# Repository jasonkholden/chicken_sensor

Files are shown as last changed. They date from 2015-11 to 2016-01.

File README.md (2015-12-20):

#4-Input Temperature Sensor Daughter Board

This is a 4-input temperature sensor daughter board for the ESP8266

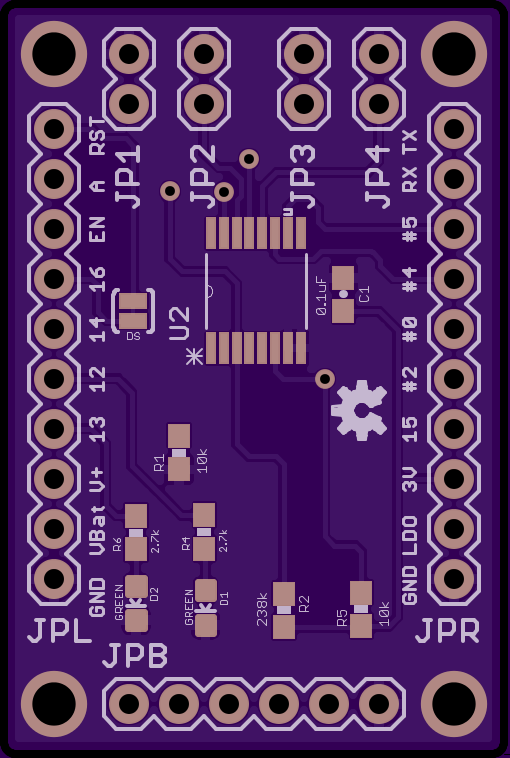
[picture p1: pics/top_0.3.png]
4-input temperature sensor Temperature Sensor


A detailed project writeup is available at [Making Electronics](http://makingelectronics.com/?q=node/3) on how to use this board to build a solar-powered IoT Temperature sensor

This daughter board will multiplex up to 4 10k thermistor inputs to the
1V-max ADC of the ESP8266.  The current form factor targets the Adafruit HUZZAH ESP8266 Breakout footprint

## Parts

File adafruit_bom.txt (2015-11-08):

Adafruit HUZZAH ESP8266 Breakout
http://www.adafruit.com/products/2471

Large 6V 3.4W Solar panel - 3.4 Watt
http://www.adafruit.com/product/500

Lithium Ion Battery - 3.7v 2000mAh
http://www.adafruit.com/product/2011

10K Precision Epoxy Thermistor - 3950 NTC
http://www.adafruit.com/products/372

Charger Options:
USB LiIon/LiPoly charger - v1.2
http://www.adafruit.com/products/259

USB / DC / Solar Lithium Ion/Polymer charger - v2
http://www.adafruit.com/products/390

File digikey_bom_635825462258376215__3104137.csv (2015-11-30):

Digi-Key Part Number | Manufacturer | Manufacturer Part Number | Customer Reference | Quantity 1 | Quantity 2 | Quantity 3 | Mfg Std Lead Time | Description | Comments | RoHS Status | Lead Free Status | REACH Status
296-9226-1-ND | TEXAS INSTRUMENTS (VA) | CD74HC4067SM96 |  | 1 | 0 | 0 | 6 Weeks | IC MUX/DEMUX 1X16 24SSOP | Alternate Packaging Exists | RoHS Compliant | Lead free | Unaffected Dec-2014
311-1343-1-ND | YAGEO (VA) | CC0603ZRY5V9BB104 |  | 1 | 0 | 0 | 21 Weeks | CAP CER 0.1UF 50V Y5V 0603 | Alternate Packaging Exists | RoHS Compliant | Lead free | Unaffected Jun-2015
311-10KGRCT-ND | YAGEO (VA) | RC0603JR-0710KL |  | 3 | 0 | 0 | 22 Weeks | RES SMD 10K OHM 5% 1/10W 0603 | Alternate Packaging Exists | RoHS Compliant | Lead free | Unaffected Jun-2015
311-2.7KGRCT-ND | YAGEO (VA) | RC0603JR-072K7L |  | 2 | 0 | 0 | 22 Weeks | RES SMD 2.7K OHM 5% 1/10W 0603 | Alternate Packaging Exists | RoHS Compliant | Lead free | Unaffected Jun-2015
160-1446-1-ND | LITE-ON INC (VA) | LTST-C191KGKT |  | 2 | 0 | 0 | 10 Weeks | LED GREEN CLEAR 0603 SMD | Alternate Packaging Exists | RoHS Compliant | Lead free | Not Available
S7039-ND | SULLINS CONNECTOR SOLUTIONS | PPPC061LFBN-RC |  | 1 | 0 | 0 | 4 Weeks | CONN HEADER FEMALE 6POS .1" GOLD |  | RoHS Compliant | Lead free | Unaffected Dec-2014
S7008-ND | SULLINS CONNECTOR SOLUTIONS | PPTC101LFBN-RC |  | 2 | 0 | 0 | 4 Weeks | CONN HEADER FEMALE 10POS.1" TIN |  | RoHS Compliant | Lead free | Unaffected Dec-2014
S7000-ND | SULLINS CONNECTOR SOLUTIONS | PPTC021LFBN-RC |  | 4 | 0 | 0 | 4 Weeks | CONN HEADER FEMALE 2POS .1" TIN |  | RoHS Compliant | Lead free | Unaffected Dec-2014
CP-035D-ND | CUI INC | PJ-035D |  | 1 | 0 | 0 | 10 Weeks | CON PWR JCK 1.3 X 3.8MM |  | RoHS Compliant | Lead free | Not Available
P237KDBCT-ND | PANASONIC ELECTRONIC COMPONENTS (VA) | ERA-3AEB2373V |  | 1 | 0 | 0 | 8 Weeks | RES SMD 237K OHM 0.1% 1/10W 0603 |  | RoHS Compliant | Lead free | Unaffected Dec-2014

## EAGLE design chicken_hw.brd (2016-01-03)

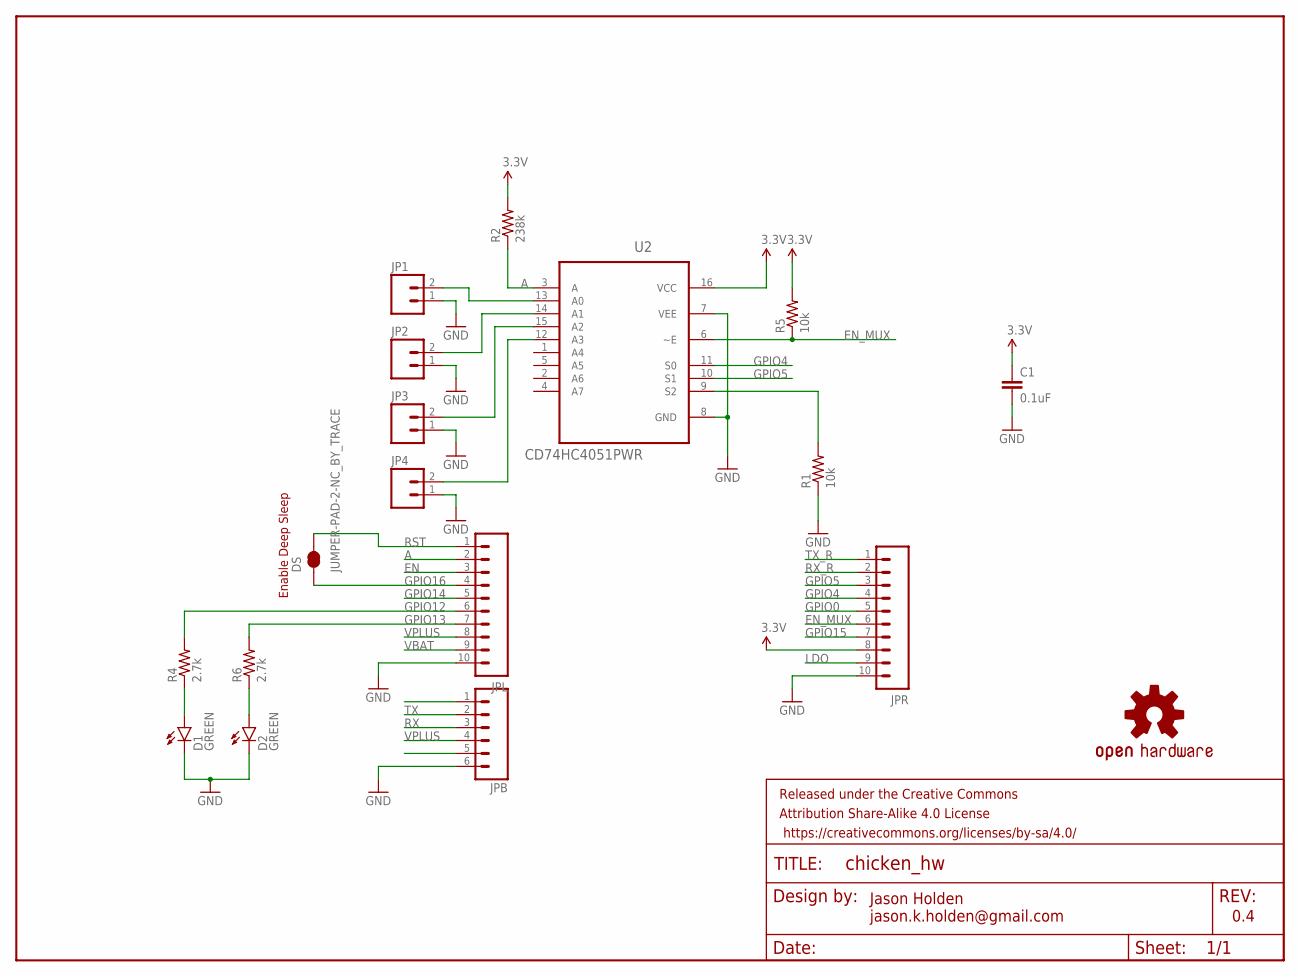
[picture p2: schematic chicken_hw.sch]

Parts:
C1: 0.1uF; 0603-CAP
D1, D2: GREEN; LED-0603
DS: JUMPER-PAD-2-NC_BY_TRACE; PAD-JUMPER-2-NC_BY_TRACE_YES_SILK
FRAME1: FRAME-LETTER; CREATIVE_COMMONS
JP1, JP2, JP3, JP4: M02PTH; 1X02
JPB: M06SILK_FEMALE_PTH; 1X06
JPL: M10SILK_FEMALE_PTH; 1X10
JPR: M10SILK_FEMALE_PTH; 1X10
LOGO1: OSHW-LOGOS; OSHW-LOGO-S
R1, R5: 10k; 0603-RES
R2: 238k; 0603-RES
R4, R6: 2.7k; 0603-RES
U2: CD74HC4051PWR; SOP65P640X120-16N

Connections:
3.3V: C1.1, JPR.8, R2.2, R5.2, U2.16 (VCC)
A: JPL.2, R2.1, U2.3 (A)
EN: JPL.3
EN_MUX: JPR.6, R5.1, U2.6 (~E)
GND: C1.2, D1.C, D2.C, JP1.1, JP2.1, JP3.1, JP4.1, JPB.6, JPL.10, JPR.10, R1.1, U2.7 (VEE), U2.8 (GND)
GPIO0: JPR.5
GPIO4: JPR.4, U2.11 (S0)
GPIO5: JPR.3, U2.10 (S1)
GPIO12: JPL.6, R4.2
GPIO13: JPL.7, R6.2
GPIO14: JPL.5
GPIO15: JPR.7
GPIO16: DS.1, JPL.4
LDO: JPR.9
unnamed: R1.2, U2.9 (S2)
unnamed: JP1.2, U2.13 (A0)
unnamed: JP2.2, U2.14 (A1)
unnamed: JP3.2, U2.15 (A2)
unnamed: JP4.2, U2.12 (A3)
unnamed: D1.A, R4.1
unnamed: D2.A, R6.1
RST: DS.2, JPL.1
RX: JPB.3
RX_R: JPR.2
TX: JPB.2
TX_R: JPR.1
VBAT: JPL.9
VPLUS: JPB.4, JPL.8

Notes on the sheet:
Jason Holden jason.k.holden@gmail.com
Enable Deep Sleep
0.4

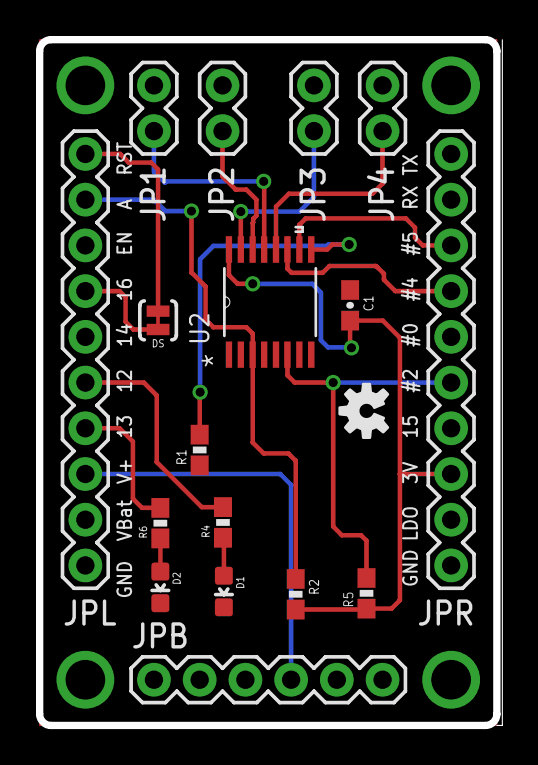
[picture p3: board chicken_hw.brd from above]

Board: 2 copper layers, 25.4 x 38.1 mm, 19 parts (0 on the bottom side), 18 nets.

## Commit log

2015-11-07 Initial project setup for a chicken coop temperature sensor
2015-11-07 Add nets and connectors for breakout board for Adafruit HUZZAH ESP8266
    [chicken_hw.brd, chicken_hw.sch]
2015-11-07 Start adding analog mux to design
    [chicken_hw.brd, chicken_hw.sch]
2015-11-08 Rough placement of components on board design
    [chicken_hw.brd, chicken_hw.sch]
2015-11-08 Add connector text to board design
    [chicken_hw.brd]
2015-11-08 Final initial placement of components, ready for autorouting
    [chicken_hw.brd, chicken_hw.sch]
2015-11-08 Improve lettering thickness on SMT parts
    [chicken_hw.brd]
2015-11-08 Bevel edges of dimensions layer
    [chicken_hw.brd]
2015-11-08 First complete routing of board, 2 vias
    [chicken_hw.brd, chicken_hw.sch]
2015-11-08 Add digikey bom for SMT parts
    [digikey_bom_635825462258376215__3104137.csv]
2015-11-08 Add to bom a DC power jack compatible with solar power supply
    [digikey_bom_635825462258376215__3104137.csv]
2015-11-08 Add two leds to gpio 16,14 for easy status
    [chicken_hw.brd, chicken_hw.sch]
2015-11-08 Finish touchup of autorouter traces manually
    [chicken_hw.brd]
2015-11-08 Update BOM with LED and led resistors
    [digikey_bom_635825462258376215__3104137.csv]
2015-11-08 Add designer information and schematic frame
    [chicken_hw.brd, chicken_hw.sch]
2015-11-08 Add open source hardware logo and bottom silk
    [chicken_hw.brd, chicken_hw.sch]
2015-11-08 Add ver0.1 gerbers ready for OSH Park to fabricate
2015-11-08 Add connectors to BOM
    [digikey_bom_635825462258376215__3104137.csv]
2015-11-08 Replace dc jack in BOM since current part selection was out of stock
    New part is slightly more expensive
    [digikey_bom_635825462258376215__3104137.csv]
2015-11-08 Add bom for adafruit
2015-11-15 Enable ESP8266 deepsleep by connecting GPIO16 to RESET - bump to ver 0.2
    Remove led's on GPIO 16,14 and move them to GPIO 12, 13
    [chicken_hw.brd, chicken_hw.sch]
2015-11-15 Add gerbers submitted to OSH Park on 11/15/2015
2015-11-15 Replace connector. Previous connector didn't mate with solar panel
    [digikey_bom_635825462258376215__3104137.csv]
2015-11-15 Revert "Replace connector. Previous connector didn't mate with solar panel"
    This reverts commit 5334f3598c814a8855e17c09d457e76b308023c7.
    Parts do indeed mate, the fit is just _very_ tight. Since the hi-current
    part is readily available on digikey, go back to it, even though its a little
    more expensive. Either part will work going forward though.
    [digikey_bom_635825462258376215__3104137.csv]
2015-11-30 Fix bom to use 0603 237k reistor, not 0805
    [digikey_bom_635825462258376215__3104137.csv]
2015-12-14 Switch to 8to1 mux to save on cost
    [chicken_hw.brd, chicken_hw.sch]
2015-12-14 Fully routed 8:1 mux, ready for production
    [chicken_hw.brd, chicken_hw.sch]
2015-12-14 Add gerbers submitted to OSH Park on 12/13/2015
2015-12-14 Add BOM for 0.3 board
    [8to1_bom.csv]
2015-12-20 Include screenshot of latest board in readme
2016-01-03 Fix ERC errors w/ V0.3 board VCC and S2 not connected (unrouted)
    [chicken_hw.brd, chicken_hw.sch]
2016-01-03 Route missing signals for mux from 12c953b27b064bb54cf89404
    [chicken_hw.brd]
2016-01-03 Rev silkscreen to ver 0.4
    [chicken_hw.brd, chicken_hw.sch]
2016-01-03 Control v0.4 gerber files submitted to OSHPark for fabrication

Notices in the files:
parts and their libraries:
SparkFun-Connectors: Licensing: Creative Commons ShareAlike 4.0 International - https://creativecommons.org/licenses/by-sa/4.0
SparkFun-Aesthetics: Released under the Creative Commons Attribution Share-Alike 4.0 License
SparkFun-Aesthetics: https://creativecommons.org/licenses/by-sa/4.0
